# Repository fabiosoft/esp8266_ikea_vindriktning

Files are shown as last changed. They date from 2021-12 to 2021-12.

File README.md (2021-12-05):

# Ikea Hack: Making the air quality sensor VINDRIKTNING smart sensor

> Do you want to know more about the air you breath in your home? Check the air quality based on particles (PM2.5) with this stylish and easy-to-use sensor.
> 	
> This sensor checks the air quality by detecting particles (PM2.5) in your home.Use your own power cord and adapter to easily turn on and use the sensor. You just need to connect it to a USB-C cable and wait a few seconds.A light indicates three levels of air quality – green (good), yellow (ok), and red (not good).Recommended to combine with FÖRNUFTIG air purifier. When the air quality is not good in your home, turn on FÖRNUFTIG air purifier to enjoy a good level of indoor air quality.Place it in the living room, bedroom, or other rooms where you spend a lot of time. With its small size, you can easily move it from room to room so you can rest assured that the air quality is good.Works just as well in small and large rooms, since the air quality is usually similar throughout a room.Its small and slim design makes the sensor blend in well with your decor.USB-C cable and USB power adapter are sold separately.
> Ikea Website, Article Number: 605.159.11

Now you have two paths… go simple and just passively sniff sensor values and send over Wi-Fi or get a full control of device and be able to control the fan, control the led separately and make all automations like night mode or light effects.

If you choose the second path you will get complete control over the device.

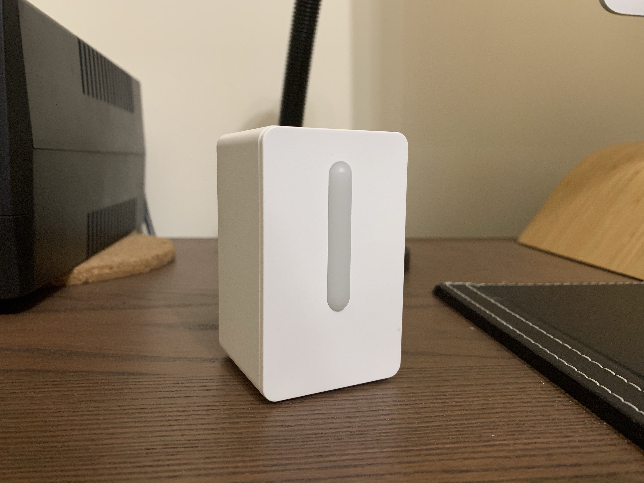
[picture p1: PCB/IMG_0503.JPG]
Final product


More info here: [www.fabiosoft.com ](https://www.fabiosoft.com/2021/12/02/ikea-hack-making-the-air-quality-sensor-vindriktning-smart-sensor/)

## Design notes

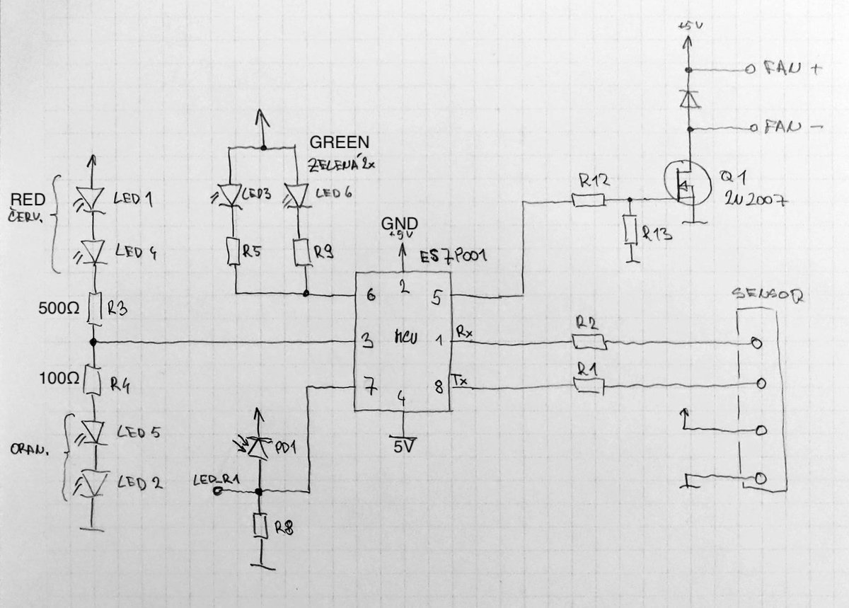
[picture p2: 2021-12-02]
Vindriktning schematic_Foto 19-08-21, 14 46 02.jpg

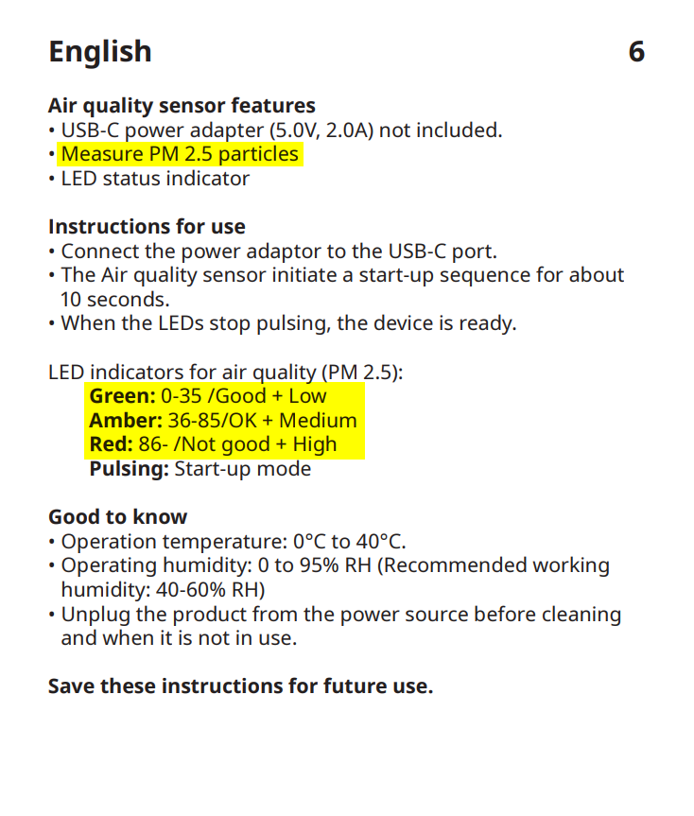
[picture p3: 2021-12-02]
user info.png

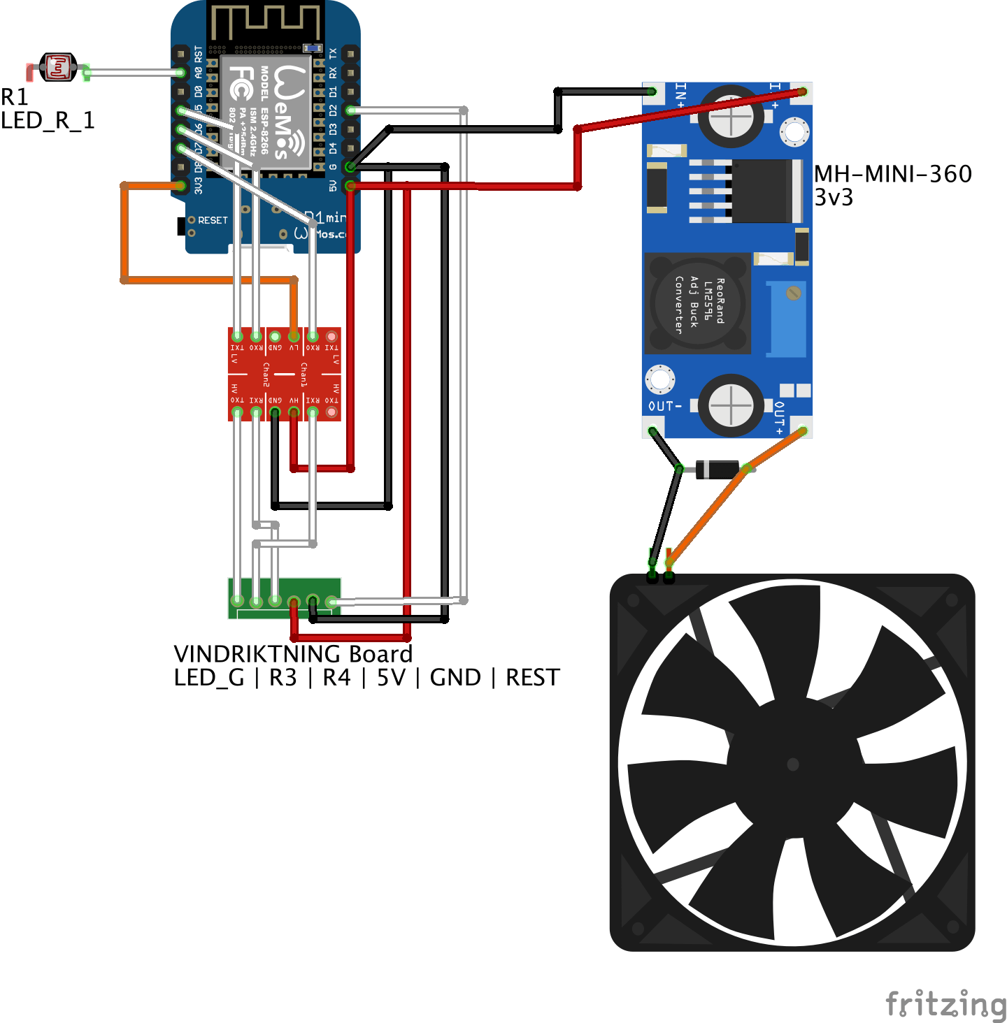
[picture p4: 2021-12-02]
PCB/pcb_VINDRIKTNING_bb.png

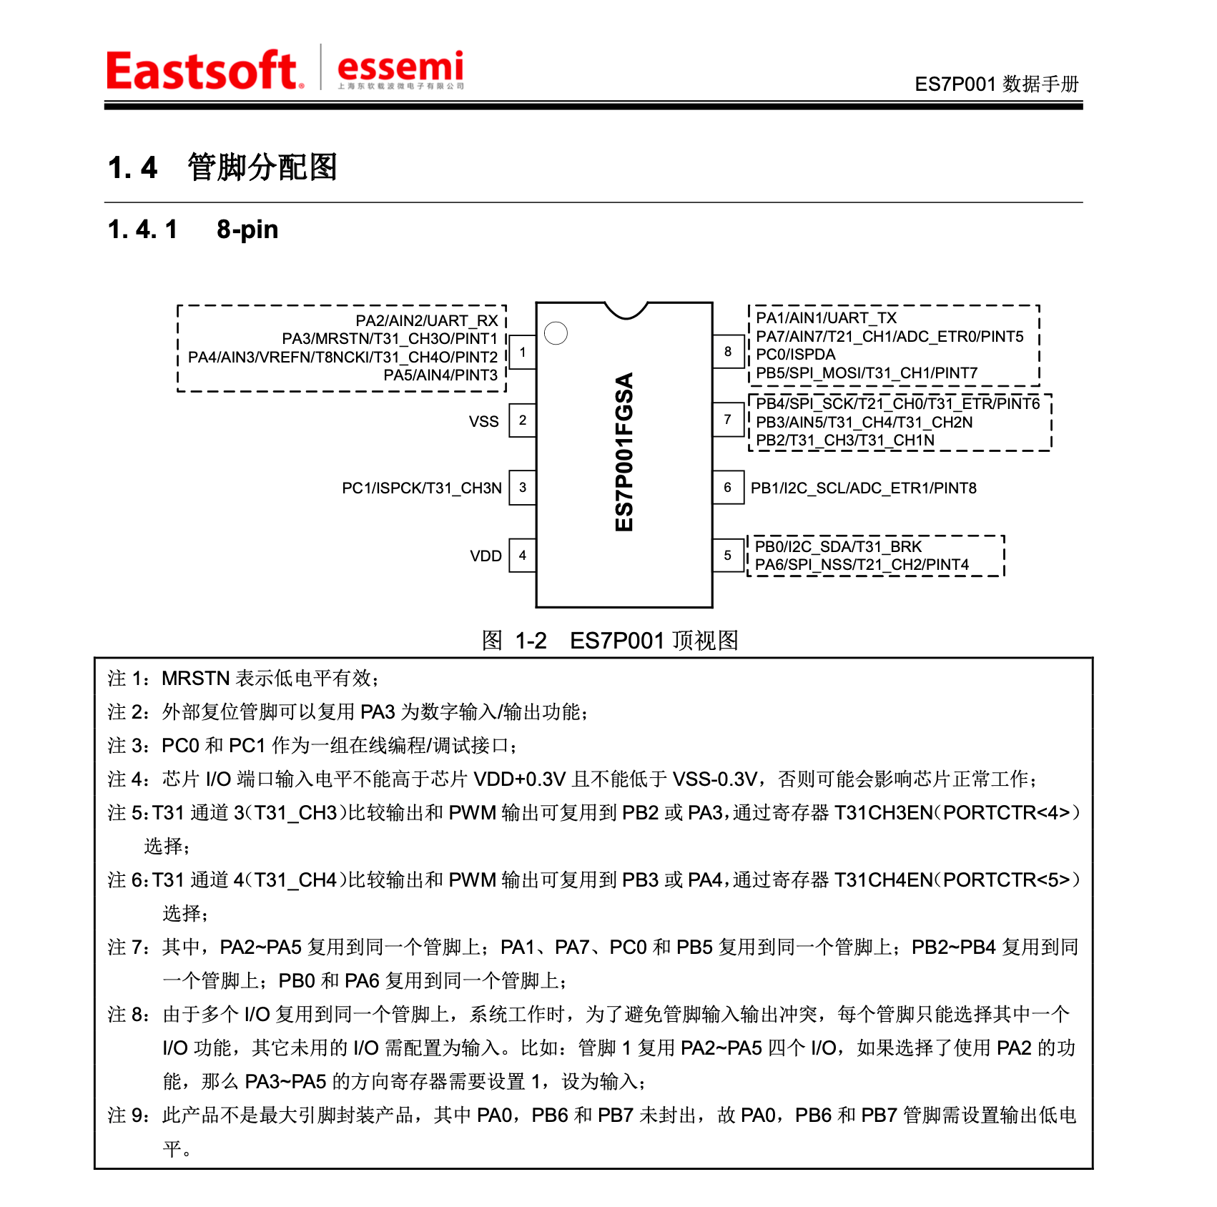
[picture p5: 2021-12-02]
datasheets/ES7P001_8pin.png

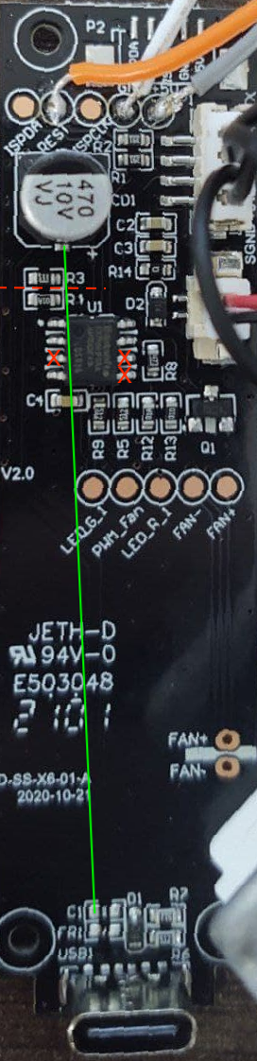
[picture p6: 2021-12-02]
PCB/VINDRIKTNING_board.png

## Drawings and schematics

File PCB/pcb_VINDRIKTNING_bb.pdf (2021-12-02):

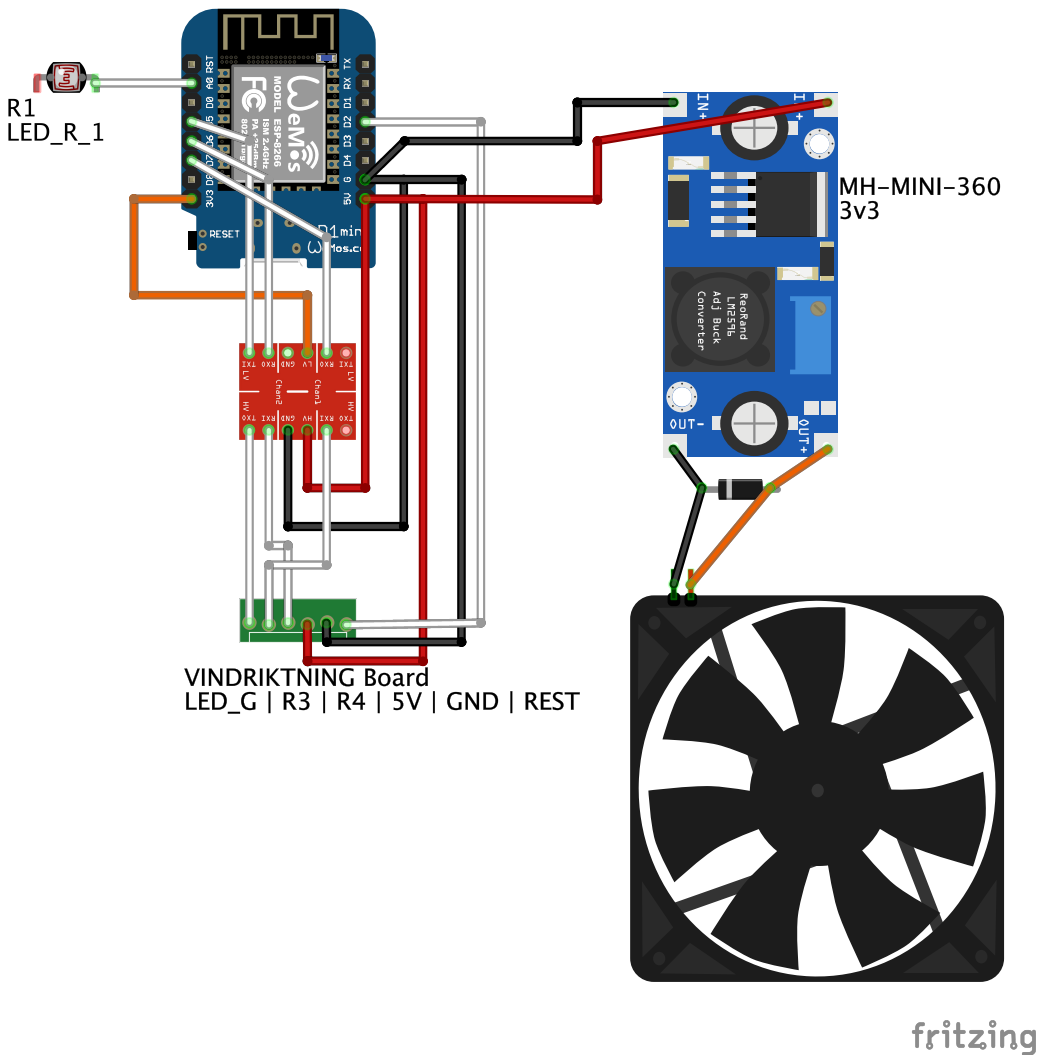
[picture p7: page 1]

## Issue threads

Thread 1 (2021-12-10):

Faint yellow LEDs

cahir1987, 2021-12-10:
Hi, thanks for your project. Everything is working. I have only problem with weakly lit yellow leds. After lighting them they are very dark light. I cut the path between R3 and R4 only on the length of resistors. Is it supposed to be like this? I measured left legs of resistors and they are not both connected. I did not cut the C1 path to the capacitor and I did not connect the path witch a wire. Do you have any idea what the problem is?

fabiosoft, 2021-12-13:
Yes, same effect for me... yellow led it's weak.
I suppose there is not enought voltage (although i used a level shifter) due to it's the only one logically not inverted.

Can you measure voltage output and across led?

Closed 2021-12-10.

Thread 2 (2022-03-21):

Orange LED issues

daniel-hofer, 2022-03-21:
Hi,
thank you for the great project! I was already looking for the possibility to use the vindriktning as traffic light alerting system in homeassistant for other things like air-quality.
So I'm very happy to got an walkthrough with your project.
But I have some issues with the orange LED.
I've all modified like in your description. Was not shure about the right lenght of the cut between R3 and R4 and did it like your red line. So all works great in ESPHome but the Orange LED switches on only very very weak - same as at the start-up sequence.
Can you give me a hint, to fix this?
Thanks a log,
kind regards
Daniel

fabiosoft, 2022-03-21:
Hi, as you can see, i have a similar problem and also some other people (with diffrent hacks).
I'm still working on to solve this, i think there is a missing ground, but i can't find where...any idea is appreciated.

Let me know...bye

daniel-hofer, 2022-03-21:
Thank you for the fast response. I have not read it anywhere that there is a problem with the orange LEDs - I cut my second device because I thought it was my fault and a damage regarding to soldering wrong.
Could you pleas be so kind and write this at the beginning of the description to avoid soneone else to damage more than one device?
If you need an voluntary for testing, I'll help!
Have a nice evening

brijins, 2022-11-03:
I had the same issue and I ended up placing couple of ws2812s in front of the board and started using them for indication. They fit nicely in there and are much brighter than the stock leds.
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

martiesim, 2023-01-26:
I had this issue too and it seemed to be the logic level shifter - at least in my case it was, though I'm using a different one than is pictured in this project.

The fix is quite easy: I took a BC337-25 transistor and soldered it as follows:
collector - 5V
base - D1 Mini's pin for the orange LEDs
emitter - the wire leading to the ikea board for the orange LEDs

This way the orange leds now work perfectly for me. I hope this is helpful for others :)

MrC0nst, 2023-10-25:
Or you can do this hardmod. But ws28** is preffered :-)
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

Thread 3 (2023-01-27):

Sensor reads only 0

martiesim, 2023-01-27:
The original ikea board doesn't let the fan spin all the time, while the hack does, but slower.

After some time I noticed the sensors readings dropping to 0 and staying there.
I suspected that the constantly spinning fan might be the cause and disconnected it.
The readings started to rise again until they reached a plausible level.

I suspect the ikea board stops the fan for the sensor to have a chance get a reading.

The solution to the problem for me was to keep the ikea boards controll over the fan intact.
To get it to be quieter I cut the fans red (+) wire and soldered a  33 ohm resistor into it.

(Of course to have the ikea board control the fan, you should not cut the ICs pin 5, or reconnect it if possible if you already did)

I hope this is helpful for someone :)

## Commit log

2021-12-02 flashing! 🚀
2021-12-02 added folder structure
    [pcb_VINDRIKTNING.fzz]
2021-12-02 added night mode and night mode switch
2021-12-05 new switch for good mode (turn on led only on orange and red not green)
